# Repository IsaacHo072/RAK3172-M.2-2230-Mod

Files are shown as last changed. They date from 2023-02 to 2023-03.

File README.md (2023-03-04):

# RAK3172-M.2-2230-Mod
M.2 Custom Module PCB for RAK3172 LoRa Radio

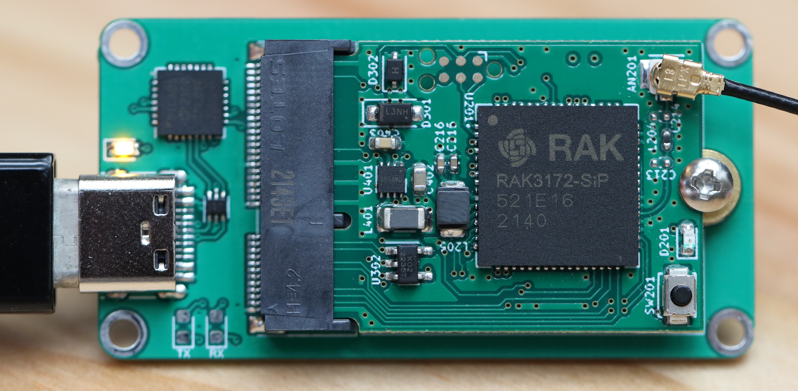
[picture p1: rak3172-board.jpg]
Photo of PCB


This PCB route the UART, I2C, SPI signals of the RAK3172 LoRa Radio to a M.2 E-key connector, in 2230 form factor.
The connector pinout is compatible with the Sparkfun M.2 "MicroMod Function Board", but without any GPIO pins provided.

It provides a onboard DC-DC supply, capable of 3.3-5.5V input, to provide power to the RAK3172. 

A EEPROM is also connected to the I2C lines. 

The board can be programmed using a Tag-Connect TC2030-IDC-NL programming cable, with a SWD programmer.

The board can be tested with a computer using the USB UART converter board.

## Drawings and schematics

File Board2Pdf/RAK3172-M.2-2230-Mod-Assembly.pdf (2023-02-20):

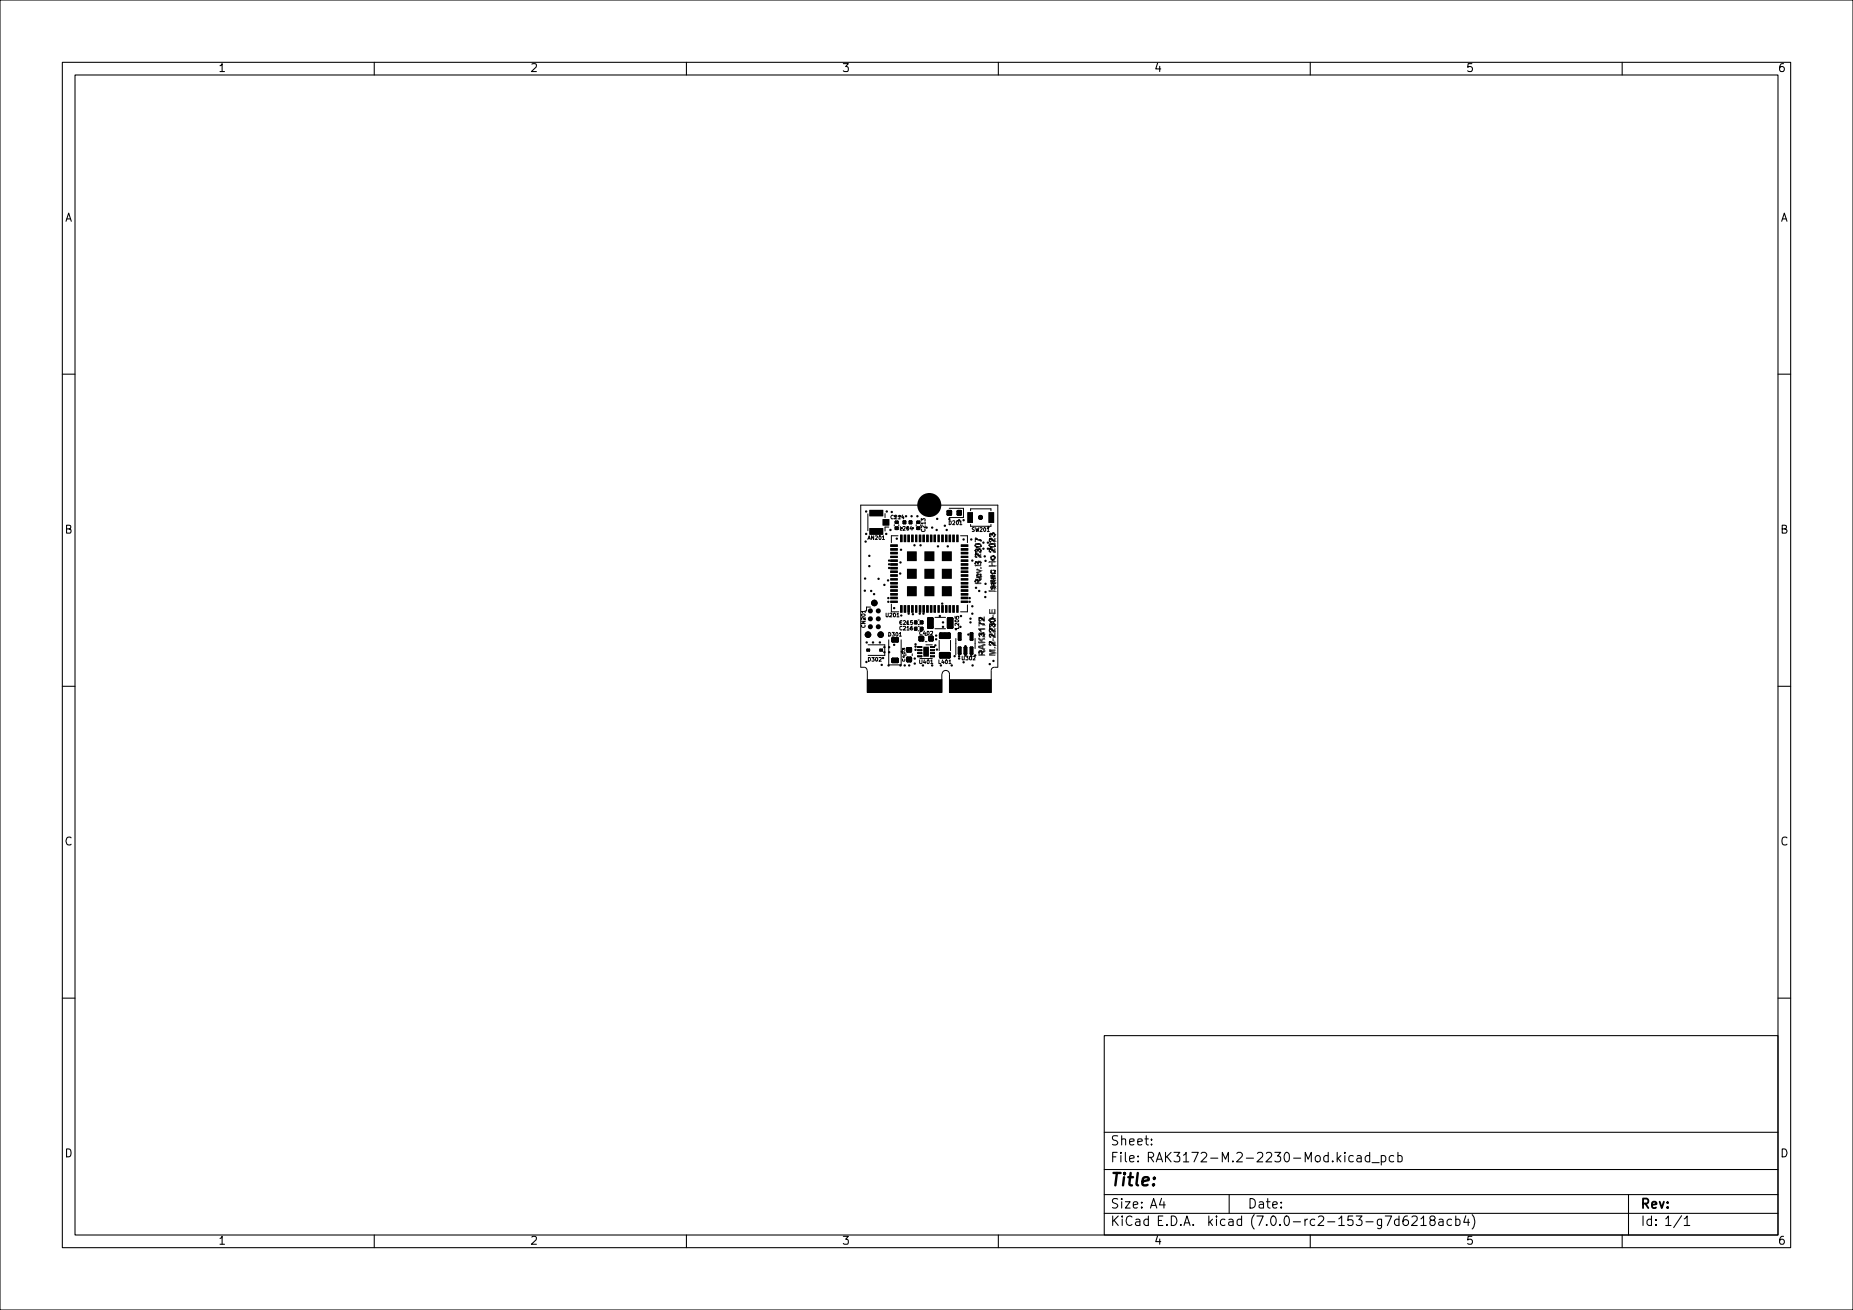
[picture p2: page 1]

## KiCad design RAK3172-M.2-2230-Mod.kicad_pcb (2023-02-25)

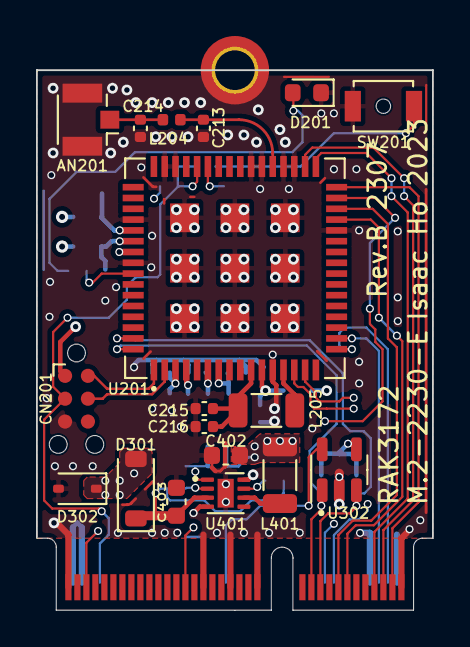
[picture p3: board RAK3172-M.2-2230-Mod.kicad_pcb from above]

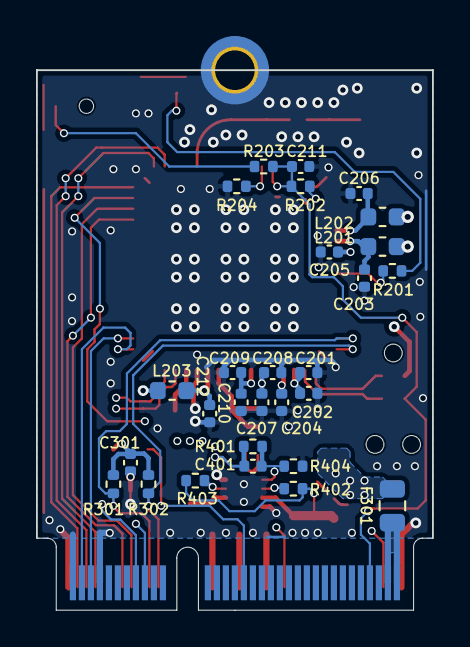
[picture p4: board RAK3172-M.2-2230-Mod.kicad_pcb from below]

Board: 4 copper layers, 22.0 x 30.0 mm, 48 parts (28 on the bottom side), 36 nets.

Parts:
AN201: Conn_Coaxial; U.FL_Hirose_U.FL-R-SMT-1_Vertical
C201, C207: 4.7uF; C_0402_1005Metric
C202, C205, C208, C210, C211, C212, C216, C301: 100nF; C_0402_1005Metric
C203, C204, C206, C209: 1uF; C_0402_1005Metric
C213, C214: DNF; C_0402_1005Metric
C215: 470nF; C_0402_1005Metric
C401: 10pF; C_0402_1005Metric
C402: 22uF; C_0603_1608Metric
C403: 10uF; C_0603_1608Metric
CN201: Conn_ARM_SWD_TagConnect_TC2030-NL; Tag-Connect_TC2030-IDC-NL_2x03_P1.27mm_Vertical
D201: LED; LED_0603_1608Metric
D301: D_Schottky; D_SOD-123
D302: 5V; D_SOD-323
F301: 0.5A; Fuse_0805_2012Metric
H301: MountingHole_Pad; MountingHole_2.2mm_M2_DIN965_Pad_TopBottom
J301: Conn_02x38_Odd_Even; NGFF_E
L201, L202, L203: 120; L_0603_1608Metric
L204: 0R; L_0402_1005Metric
L205: 15uH; L_1206_3216Metric
L401: 1uH; L_1206_3216Metric
R201, R301, R302: 3.3k; R_0402_1005Metric
R202, R204: 10k; R_0402_1005Metric
R203: 1k; R_0402_1005Metric
R401, R402, R403: 100k; R_0402_1005Metric
R404: 22.1k; R_0402_1005Metric
SW201: SW_SPST; SW_SPST_B3U-1000P-B
U201: RAK3172-SIP; LGA-73_12x12mm_P0.6mm
U302: 24LC01; SOT-23-5
U401: SY8883DFC; DFN-8-1EP_2x2mm_P0.5mm_EP0.9x1.6mm

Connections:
3.3V: C201.1, C202.1, C204.1, C205.1, C207.1, C208.1, C209.1, C210.1, C301.1, C401.1, C402.1, CN201.1 (VCC), L201.2, L202.2, L203.1, L401.2, R202.2, R301.1, R302.1, R401.1, U201.3 (VDD), U201.4 (VBAT), U201.6 (VREF+), U201.7 (VDDA), U201.55 (VDD), U302.4 (VCC)
+5V: C403.1, D301.1 (K), R402.1, R403.1, U401.3 (IN)
/M.2 E-Key Connector/EEPROM_WP: J301.40, U302.5 (WP)
/M.2 E-Key Connector/V_{CC}Fused: D301.2 (A), D302.1 (A1), F301.2
/Power Supply/3.3VPG: R402.2, U401.2 (PG)
/RAK3172/BOOT0: R204.1, U201.43 (BOOT_0)
/RAK3172/PA13/SWDIO: CN201.2 (SWDIO), U201.1 (PA13)
/RAK3172/PA14/SWCLK: CN201.4 (SWCLK), U201.2 (PA14)
/RAK3172/PB1: R201.1, U201.57 (PB1)
/RAK3172/RF_OUT: C213.1, L204.1, U201.37 (RF_OUT)
/RAK3172/RF_OUT_CONN: AN201.1 (In), C214.1, L204.2
/RAK3172/VDDPA: C206.1, L202.1, U201.53 (VDDPA)
/RAK3172/VDDRF: C203.1, L201.1, U201.54 (VDDRF)
/RAK3172/VDDSMPS: C212.1, L203.2, U201.11 (VDDMPS)
/RAK3172/VFBSMPS: C215.1, C216.1, L205.1, U201.10 (VFBSMPS)
/RAK3172/VLXSMPS: L205.2, U201.13 (VLXSMPS)
CTS: J301.18, U201.15 (PB4)
DFU_FC_RX: J301.6, U201.18 (PB7/UART1_RX)
DFU_FC_TX: J301.4, U201.17 (PB6/UART1_TX)
DFU_~RST: C211.1, CN201.3 (~RESET), J301.68, R202.1, R203.2, U201.44 (NRST)
F1/~CS: J301.49, U201.31 (PA4)
GND: AN201.2 (Ext), C201.2, C202.2, C203.2, C204.2, C205.2, C206.2, C207.2, C208.2, C209.2, C210.2, C211.2, C212.2, C213.2, C214.2, C215.2, C216.2, C301.2, C402.2, C403.2, CN201.5 (GND), D201.1 (K), D302.2 (A2), H301.1, J301.1, J301.2, J301.8, J301.33, J301.39, J301.45, J301.75, R204.2, R404.2, SW201.1 (A), U201.12 (GND), U201.28 (GND), U201.35 (GND), U201.36 (GND), U201.38 (GND), U201.39 (GND), U201.46 (GND), U201.47 (GND), U201.52 (GND), U201.56 (GND), U201.65 (GND), U201.66 (GND), U201.67 (GND), U201.68 (GND), U201.69 (GND), U201.70 (GND), U201.71 (GND), U201.72 (GND), U201.73 (GND), U302.2 (VSS), U401.4 (PGND), U401.8 (AGND), U401.9 (PGND)
I2C_SCL: J301.21, R302.2, U201.64 (PA12), U302.1 (SCL)
I2C_SDA: J301.19, R301.2, U201.63 (PA11), U302.3 (SDA)
unnamed: D201.2 (A), R201.2
unnamed: R203.1, SW201.2 (B)
unnamed: C401.2, R401.2, R404.1, U401.1 (FB)
unnamed: L401.1, U401.6 (LX)
PWR_EN: J301.71, R403.2, U401.7 (EN)
RTS: J301.16, U201.14 (PB3)
RX: J301.15, U201.30 (PA3/UART2_RX)
SPI_SCK: J301.3, U201.32 (PA5)
SPI_SDI: J301.5, U201.34 (PA7)
SPI_SDO: J301.7, U201.33 (PA6)
TX: J301.13, U201.29 (PA2/UART2_TX)
VCC: F301.1, J301.72, J301.74

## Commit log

2023-02-25 Updated 3D model of 1206 inductor to 1210
    [RAK3172-M.2-2230-Mod.kicad_pcb]
2023-03-02 Moved board pdf
2023-03-04 Added board photo
